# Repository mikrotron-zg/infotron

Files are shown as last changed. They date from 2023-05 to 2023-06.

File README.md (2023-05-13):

# Infotron

Simple info screen (e.g. LED matrix) displaying information from different web sources via wifi MCU (ESP32). This demo program allows you to display:
* time and date, 
* weather info, 
* custom text,
* or anything else you program it to display :wink:

Infotron runs its own little web server and web application that allows you to choose what to display. You can acces it via smartphone, tablet or notebook, by connecting directly to Infotron's access point (AP) or through your local network. Open your favorite browser and enter the IP address that Infotron scrolls at startup and have some fun _(Note: if you're not connecting to Infotron's AP, you'll have to find out the IP address it's assigned by your router first_).

## 1. Hardware

This project is built around two main components:
* [D1 MINI ESP32](https://www.diykits.eu/products/p_11918)
* [MAX7219 4-in-1 LED Matrix Display](http://www.diykits.eu/products/p_10987)

### 1.1. Wiring

Wiring is simple, follow the instructions in main.cpp, use fritzing file in _doc_ directory or the image below for reference:

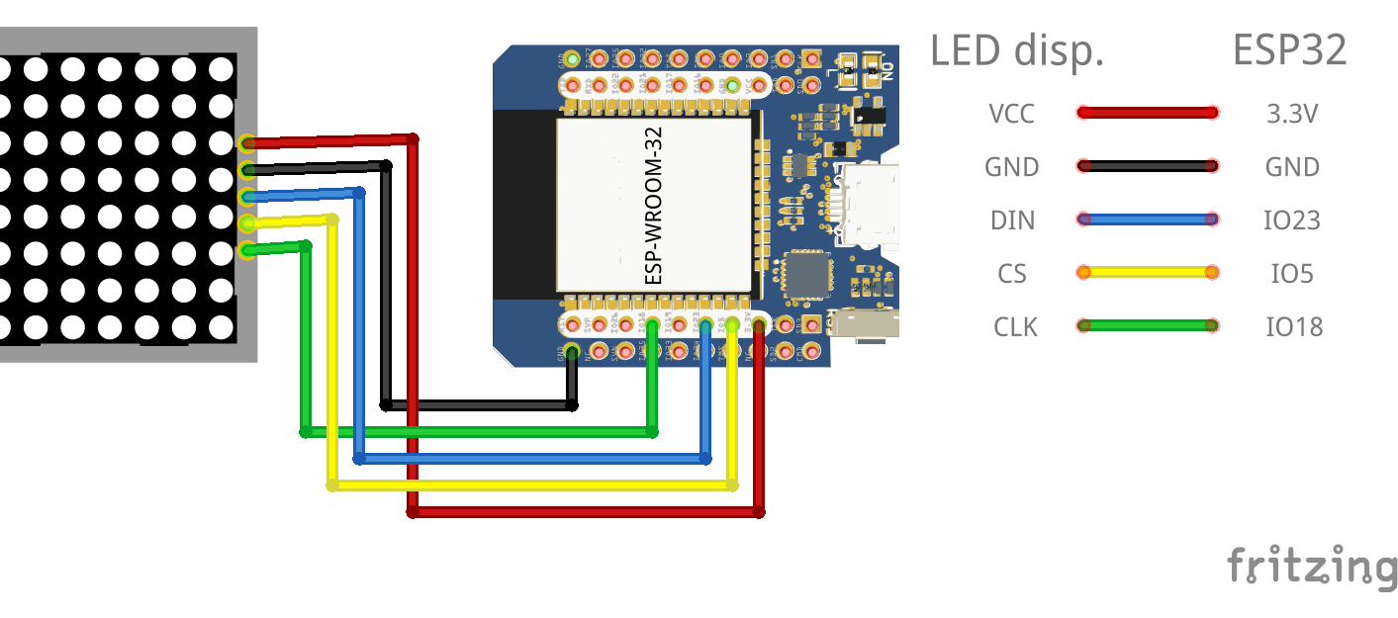
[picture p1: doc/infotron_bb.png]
Infotron wiring


You can solder the wires directly or use the provided angle headers and dupont wires for connection. Once in a box, it should look like this:

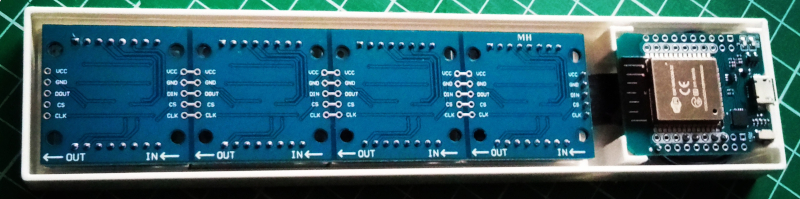
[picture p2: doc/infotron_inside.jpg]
Infotron box inside


### 1.2. Box

The box is 3D printed, 3D model was made using [OpenSCAD](https://openscad.org/) and source files are in _model_ directory. Final version of STLs will be there too, you'll have to use OpenSCAD (it's free and open source) to generate STLs. It's recommended to print in PETG, but any other filament type should be fine.

## 2. Software

To change, compile and upload this firmware, you'll need [VS Code](https://code.visualstudio.com/) and [PlatformIO plugin](https://platformio.org/). Make sure to build the filesystem image of _data_ directory and upload it to the boards SPIFFS too, as it contains the web application files needed to control Infotron. You can find out more about it [here](https://esp32tutorials.com/esp32-esp-idf-spiffs-web-server/).

### 2.1. Dependencies

The libraries used:
* [MD_Parola library](https://github.com/MajicDesigns/MD_Parola) by Marco Colli ([MajicDesigns](https://github.com/MajicDesigns))
* [MD_MAX72xx library](https://github.com/MajicDesigns/MD_MAX72xx) by Marco Colli ([MajicDesigns](https://github.com/MajicDesigns))
* [ESP Async WebServer](https://github.com/me-no-dev/ESPAsyncWebServer?utm_source=platformio&utm_medium=piohome) by [Hristo Gochkov](https://github.com/me-no-dev)

## 3. Status

Demo program on main branch works for the hardware listed above. The old (unfinished) version based on ESP8266 board can be found on branch _esp8266_.

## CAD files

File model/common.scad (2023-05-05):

/*
 * A library of common modules, functions and variables
 * This file is part of Infotron project (https://github.com/mikrotron-zg/infotron)
 * by Mikrotron d.o.o. (http://mikrotron.hr)
 *
 * This program is free software: you can redistribute it and/or modify
 * it under the terms of the GNU General Public License as published by
 * the Free Software Foundation, either version 3 of the License, or
 * (at your option) any later version. See the LICENSE file at the 
 * top-level directory of this distribution for details 
 *
 * This program is distributed in the hope that it will be useful,
 * but WITHOUT ANY WARRANTY; without even the implied warranty of
 * MERCHANTABILITY or FITNESS FOR A PARTICULAR PURPOSE.  See the
 * GNU General Public License for more details.
 *
 * You should have received a copy of the GNU General Public License
 * along with this program.  If not, see <https://www.gnu.org/licenses/>.
 */

// Extra dimension to remove ambiguity of walls
ex = 0.001;

// Hole dimension correction - if 3D printed holes turn out too small,
// increase the value (e.g. 1.1 = 110%), or reduce the value (e.g. 0.9 = 90%).
// Default value is 1.0 (100%)
hdc = 1.1;

// Some nuts and bolts dimensions
m3_bolt_head_dia = 6*hdc;
m3_bolt_head_height = 2;
m3_dia = 3*hdc;


module rounded_rect(x, y, z, radius = 1) {
    // Draws a rounded rectangle
    translate([radius,radius,0]) //move origin to outer limits
	linear_extrude(height=z)
		minkowski() {
			square([x-2*radius,y-2*radius]); //keep outer dimensions given by x and y
			circle(r = radius, $fn=100);
		}
}


module cylinder_quarter(r, h){
    // Draws quarter of a cylinder
    difference(){
        cylinder(r=r, h=h);
        translate ([-r-ex, -r-ex, -ex]) cube([2*r + 2*ex, r + ex, h + 2*ex]);
        translate ([-r-ex, -ex, -ex]) cube([r + ex, r + ex, h + 2*ex]);
    }
}


module header_pin(rows=1, columns=1){
    // Draws 2.54 mm male header pins
    base_width = 2.54;
    base_height = 2.54;
    header_width = 0.508;
    header_height = 5.08;
    trans = base_width/2 - header_width/2;

    for (i = [0: rows - 1]){
        for (j = [0: columns -1]){
            translate([j*base_width, i*base_width, 0]){
                color("Black") cube([base_width, base_width, base_height]);
                translate([trans , trans, base_height])
                    color("Khaki") cube([header_width, header_width, header_height]);
            }
        }
    }

}

module m3_bolt(length = 10){
    // M3 bolt mockup
    union(){
        cylinder(d = m3_dia, h = length);
        translate([0, 0, length - ex - m3_bolt_head_height]) 
            cylinder(d = m3_bolt_head_dia, h = m3_bolt_head_height + ex);
    }
}

module m3_nut_trap(){
    // Makes M3 nut trap inset
    cylinder(r=5.5/2/cos(180/6)*hdc, h=2, $fn=6);
}

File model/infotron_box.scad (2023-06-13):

/*
 * Infotron box 3D model
 * This file is part of Infotron project (https://github.com/mikrotron-zg/infotron)
 * by Mikrotron d.o.o. (http://mikrotron.hr)
 *
 * This program is free software: you can redistribute it and/or modify
 * it under the terms of the GNU General Public License as published by
 * the Free Software Foundation, either version 3 of the License, or
 * (at your option) any later version. See the LICENSE file at the 
 * top-level directory of this distribution for details 
 *
 * This program is distributed in the hope that it will be useful,
 * but WITHOUT ANY WARRANTY; without even the implied warranty of
 * MERCHANTABILITY or FITNESS FOR A PARTICULAR PURPOSE.  See the
 * GNU General Public License for more details.
 *
 * You should have received a copy of the GNU General Public License
 * along with this program.  If not, see <https://www.gnu.org/licenses/>.
 */
 
include<led_matrix_32x8.scad>;
include<mini32.scad>;

// Box dimensions
wall = 1.6; // box wall width
wall2 = 1.25*wall; // thicker box wall
screen_border = 2*wall + 3.0; // screen border width
box_width = led_matrix_width + 2*screen_border;
box_length = screen_border + 4*led_matrix_width + 50;
box_top_height = led_matrix_height + led_matrix_offset + module_pcb_height + wall + 0.4; 
box_bottom_height = 4 + wall2;
box_overlap_height = 5;
box_overlap_tolerance = wall/4;
slit_height = 1.5;
slit_width = wall/2;

// ESP32 mount dimensions
esp32_mount_width = 6;
esp32_mount_height = box_top_height - wall2;
esp32_mount_offset = 1;
esp32_mount_corner = esp32_mount_width - esp32_mount_offset;

// Entry point
infotron_box();

module infotron_box(){
    // Draws bottom and top part of the box, comment out one or the other for single object
    draw_bottom();
    translate([0, 1.2*box_width, 0]) draw_top();
}

module draw_bottom() {
    color ("White") difference() {
        union(){
            bottom_shell();
            // Overlap wall
            translate([wall, wall, wall2]) overlap();
            translate([box_length, box_width/2 - mini32_width/2, wall2]) 
                esp32_fixers();
            translate([screen_border + led_matrix_width/2 - esp32_mount_width/2,
                        box_width/2 - esp32_mount_width/2, wall2])
                led_matrix_fixers();
        }
        // USB cutout
        translate([box_length - 2*wall - ex, 
                   box_width/2 - mini32_usb_width/2 - 1,
                   box_bottom_height - mini32_usb_height])
            cube([3*wall, mini32_usb_width + 2, mini32_usb_height + ex]);
        // Removing corners
        translate([0, 0, box_bottom_height]) 
            cube([4*wall, 4*wall, box_overlap_height + ex]);
        translate([0, box_width - 4*wall, box_bottom_height]) 
            cube([4*wall, 4*wall, box_overlap_height + ex]);
        // Vent grill
        translate([box_length - 0.85*mini32_length, box_width/5, -ex]) {
            for (y = [0 : 5 : 3*box_width/5]) {
                translate([0, y, 0]) rounded_rect(0.75*mini32_length, 2.5, wall2 + 2*ex, 1);
            }
        }
    }
}

module bottom_shell() {
    difference(){
        rounded_rect(box_length, box_width, box_bottom_height);
        translate([wall, wall, wall2])
             cube([box_length - 2*wall, box_width - 2*wall, 
                    box_bottom_height - wall2 + ex]);
        translate([box_length*0.25, box_width/2, -ex]) wall_mount();
        translate([box_length*0.75, box_width/2, -ex]) wall_mount();
    }
}

module wall_mount() {
    $fn = 100;
    slit_width = 4;
    slit_length = 2;
    opening_dia = 8;
    translate([0, slit_length/4 + slit_width/4 + opening_dia/4]) {
        cylinder(d = slit_width, h = box_bottom_height + 2*ex);
        translate([-slit_width/2, -slit_length - slit_width/2 - opening_dia/2, 0]) 
            cube([slit_width, slit_length + slit_width/2 + opening_dia/2, box_bottom_height + 2*ex]);
        translate([0, -slit_length - opening_dia/2, 0])
            cylinder(d = opening_dia, h = box_bottom_height + 2*ex);
    }
}

module overlap() {
    inner_wall_height = box_bottom_height - wall2;
    difference() {
        cube([box_length - 2*wall, box_width - 2*wall, 
                inner_wall_height]);
        translate([wall, wall, -ex])
            cube([box_length - 2*wall, box_width - 4*wall,
                   inner_wall_height + 2*ex]);
    }
    translate([box_overlap_tolerance, box_overlap_tolerance, inner_wall_height])
    difference() {
        cube([box_length - 2*wall - 2*box_overlap_tolerance, 
                box_width - 2*wall - 2*box_overlap_tolerance, box_overlap_height]);
         translate([wall - box_overlap_tolerance, wall - box_overlap_tolerance, -ex])
            cube([box_length - 2*wall, box_width - 4*wall, box_overlap_height + 2*ex]);
    }
    translate([0, 0, inner_wall_height + box_overlap_height - 0.75*slit_height]) clips();
}

module clips() {
    clip_length = 5;
    translate([box_overlap_tolerance, box_width/2 - wall - clip_length/2, 0])
        rotate(90) clip(clip_length);
    for (i = [1 : 5]) {
        translate([i*(box_length - 2*wall)/6, -slit_width + box_overlap_tolerance, 0])
            clip(clip_length);
        translate([i*(box_length - 2*wall)/6, box_width - 2*wall - box_overlap_tolerance, 0]) 
            clip(clip_length);
    }
}

module clip(length) {
    cube([length, slit_width, 0.75*slit_height]);
}

module draw_top(){
    color ("White") {
        top_shell();
        translate([screen_border - wall, screen_border - wall, wall]) screen_bracket();
        translate([box_length - wall, box_width/2 + mini32_width/2, wall2])
            rotate(180) esp32_mount();
    }
    translate([screen_border, screen_border + led_matrix_width, led_matrix_height + led_matrix_offset + module_pcb_height]) 
            rotate([180, 0, 0]) %led_matrix_32x8();
    translate([box_length - wall, box_width/2 + mini32_width/2, box_top_height - mini32_height])
            rotate(180) %mini32();
}

module top_shell(){
    difference(){
        rounded_rect(box_length, box_width, box_top_height);
        translate([wall, wall, wall2])
            cube([box_length - 2*wall, box_width - 2*wall, box_top_height - wall2 + ex]);
        // Slit
        translate([slit_width, slit_width, box_top_height - box_overlap_height])
            cube([box_length - 2*slit_width, box_width - 2*slit_width, slit_height]);
        // Screen diffuser
        translate([screen_border, screen_border, 0.4])
            cube([4*led_matrix_width, led_matrix_width, wall2 + 2*ex]);
        // Engraved text
        translate([box_length - 50/2, box_width - screen_border, -ex]) top_text();
    }
}

module screen_bracket(bracket_height = 4){
    // Draw bracket
    difference(){
        cube([4*led_matrix_width + 2*wall, led_matrix_width + 2*wall, bracket_height]);
        translate([wall, wall, -ex])
            cube([4*led_matrix_width, led_matrix_width, led_matrix_width + 2*ex]);
    }
}

module top_text(){
    rotate([180, 0, 0]) translate([0, 0, -0.6]) linear_extrude(height = 0.6)
        text("infotron", size = 8, font = "Liberation Sans", halign = "center",                valign = "bottom");
}

module esp32_mount() {
    translate([mini32_length - esp32_mount_corner, -esp32_mount_offset, 0])
        esp32_pillar_mount();
    translate([mini32_length + esp32_mount_offset, mini32_width - esp32_mount_corner, 0])
        rotate(90) esp32_pillar_mount();
    translate([0, -esp32_mount_offset, 0]) difference() {
        cube([esp32_mount_corner, mini32_width - mini32_reset_width + 2*esp32_mount_offset, esp32_mount_height]);
        translate([0, esp32_mount_offset, esp32_mount_height - mini32_height])
            cube([esp32_mount_corner, mini32_width - mini32_reset_width, mini32_height + ex]);
    }
}

module esp32_pillar_mount() {
    difference() {
        cube([esp32_mount_width, esp32_mount_width, esp32_mount_height]);
        translate([0, 1, esp32_mount_height - mini32_height])
            cube([esp32_mount_corner, esp32_mount_corner, mini32_height + ex]);
    }
}

module esp32_fixers() {
    translate([-mini32_length - esp32_mount_offset, -esp32_mount_offset, 0])
        cube([esp32_mount_width, esp32_mount_width, box_bottom_height - wall2]);
    translate([-mini32_length - esp32_mount_offset, 
                mini32_width - esp32_mount_width + esp32_mount_offset, 0])
        cube([esp32_mount_width, esp32_mount_width, box_bottom_height - wall2]);
}

module led_matrix_fixers() {
    for (i = [0 : 3]) {
        translate([i*led_matrix_width, 0, 0])
            cube([esp32_mount_width, esp32_mount_width, box_bottom_height - wall2]);
    }
}

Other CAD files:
model/led_matrix_32x8.scad
model/mini32.scad

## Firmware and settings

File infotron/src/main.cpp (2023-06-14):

/*
 * This file is part of Infotron project (https://github.com/mikrotron-zg/infotron)
 * developed by Mikrotron d.o.o. (http://mikrotron.hr).
 * This is the main program file with setup and main program loop.
 *
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
 * You should have received a copy of the GNU General Public License
 * along with this program.  If not, see <https://www.gnu.org/licenses/>.
 */

#include <Arduino.h>
#include <MD_Parola.h> 
#include <MD_MAX72xx.h>
#include <SPI.h>
#include "Configuration.h"
#include "WebServer.h"
#include "DateTimeHandler.h"
#include "CryptoInfo.h"

/* 
  Define the number of devices we have in the chain and the hardware interface SPI connection pins
  NOTE: These pin numbers are for D1 MINI ESP 32 hardware SPI and will probably not
        work with different hardware and may need to be adapted
*/
#define HARDWARE_TYPE MD_MAX72XX::FC16_HW // works only with MD_MAX72xx 3.0.0 and up
#define MAX_DEVICES   4   // number of 8x8 LED matrix displays in use
#define CLK_PIN       18  // pinout tag: SCK
#define DATA_PIN      23  // pinout tag: MOSI
#define CS_PIN        5   // pinout tag: SS

MD_Parola screen = MD_Parola(HARDWARE_TYPE, CS_PIN, MAX_DEVICES);
DisplayMode displayMode = TEXT;

// Scrolling parameters
uint8_t frameDelay = 30;    // default frame delay value
textEffect_t scrollEffect = PA_SCROLL_LEFT;
textPosition_t scrollAlign = PA_LEFT;

// Global message buffers
#define BUF_SIZE  1024 // buffer size that should be able to handle data, increase size if needed
char curMessage[BUF_SIZE] = {""}; // message currently on display
char newMessage[BUF_SIZE] = {"Infotron starting..."}; // next message to display
bool newMessageReceived = true;

// Global datetime container
uint16_t datetime[6] = {0, 0, 0, 0, 0, 0}; // day, month, year, hour, minute, second
bool datetimeUpdated = false;

// Global weather info container
WeatherInfo weatherInfo = {0, 0, 0, false, 0};

// Global crypto info container
CryptoInfo cryptoInfo[CRYPTO_NUM] = {{"BTC", 0, 0, 0},    // Bitcoin
                                     {"ETH", 0, 0, 0}};    // Ethereum
                                     //{"DOGE", 0, 0, 0}};  // Dogecoin
int currentCryptoInfo = -1; // index of crypto info currently on display
ulong cryptoInfoLastUpdated = 0; // last time crypto info was updated

/**
 * @brief Handles custom text display.
 * 
 * Reads the contents of newMessage and sets it as a  
 * current message to display, then scrolls the message 
 * on a display.
 */
void displayText() {
  if (newMessageReceived) {
    strcpy(curMessage, newMessage);
    newMessageReceived = false;
    screen.displayScroll(curMessage, scrollAlign, scrollEffect, frameDelay);
  }
}

/**
 * @brief Handles date/time display.
 * 
 * Displays date and time received from the web app.
 */
void displayDateTime() {
  // Handle date/time display
  if (datetimeUpdated) {
    validateTime();
    if (datetime[5] == 20 || datetime[5] == 40) { // show date
      sprintf(newMessage, "%02d.%02d.%04d.", datetime[0], datetime[1], datetime[2]);
      datetimeUpdated = false;
      screen.displayClear();
      screen.displayScroll(newMessage, scrollAlign, scrollEffect, frameDelay*1.5);
      return;
    }
    if (datetime[5]%2 == 0) { // show time
      sprintf(curMessage, "%02d:%02d", datetime[3], datetime[4]);
    } else {
      sprintf(curMessage, "%02d %02d", datetime[3], datetime[4]);
    }
    datetimeUpdated = false;
    screen.displayText(curMessage, PA_CENTER, screen.getSpeed(), 0, PA_NO_EFFECT, PA_NO_EFFECT);
  }
}

/**
 * @brief Handles weather info display.
 * 
 * Displays weather info received from external source.
 */
void displayWeatherInfo() {
  // Handle weather info display
  if (!weatherInfo.isValid) { // no internet connection or server failure
    sprintf(newMessage, "Can't access weather data");
    newMessageReceived = true;
    displayMode = TEXT;
    return;
  }

  if (weatherInfo.showing == 0) { // first time showing weather info
    sprintf(curMessage, "%d \xB0""C", weatherInfo.temp);
    screen.displayText(curMessage, PA_CENTER, screen.getSpeed(), MAX_SCREEN_TIME, PA_GROW_UP, PA_GROW_DOWN);
    weatherInfo.showing++;
    return;
  }

  switch (weatherInfo.showing) {
    case 1:
      sprintf(curMessage, "%d%% RH", weatherInfo.humidity);
      screen.displayText(curMessage, PA_CENTER, screen.getSpeed(), MAX_SCREEN_TIME, PA_GROW_UP, PA_GROW_DOWN);
      weatherInfo.showing++;
      break;
    case 2:
      sprintf(curMessage, "%dhPa", weatherInfo.pressure);
      screen.displayText(curMessage, PA_CENTER, screen.getSpeed(), MAX_SCREEN_TIME, PA_GROW_UP, PA_GROW_DOWN);
      weatherInfo.showing++;
      break;
    case 3:
      sprintf(curMessage, "%d \xB0""C", weatherInfo.temp);
      screen.displayText(curMessage, PA_CENTER, screen.getSpeed(), MAX_SCREEN_TIME, PA_GROW_UP, PA_GROW_DOWN);
      weatherInfo.showing = 1;
      break;
  }
}

/**
 * @brief Handles crypto info display.
 * 
 * Displays crypto info received from external source.
 */
void displayCryptoInfo() {
  if ((millis() - cryptoInfoLastUpdated) > CRYPTOINFO_UPDATE_INTERVAL) getCryptoInfo();
  currentCryptoInfo++;
  if (currentCryptoInfo >= CRYPTO_NUM) currentCryptoInfo = 0;
  char value[10];
  char change[10];
  dtostrf(cryptoInfo[currentCryptoInfo].value, 4, 2, value);
  dtostrf(cryptoInfo[currentCryptoInfo].change*100, 4, 2, change);
  sprintf(curMessage, "%s   $%s  (%s%%)", cryptoInfo[currentCryptoInfo].ticker, value, change);
  screen.displayScroll(curMessage, scrollAlign, scrollEffect, frameDelay);
}

/**
 * @brief Program entry point, runs only once.
 * 
 * Initializes the screen and starts web server.
 */
void setup() {
  // Read instructions on DEBUG_MODE in 'include/Debug.h' file
  #ifdef DEBUG_MODE
    Serial.begin(115200);
    delay(3000);
    DEBUGLN("Infotron started in debug mode");
  #endif

  // Mount SPIFFS file system
  if(!SPIFFS.begin()){
    DEBUGLN("SPIFFS mounting error");
  }

  // Initailizing MD_Parola
  screen.begin();
  screen.displayClear();
  screen.displaySuspend(false);

  // Show start message
  displayText();

  // Start web server
  startWebServer();
}

/**
 * @brief Program main loop.
 * 
 * Handles screen display mode.
 */
void loop() {
  if (screen.displayAnimate()) {
    switch (displayMode) {
      case TEXT:
        displayText();
        screen.displayReset();
        break;
      case DATETIME:
        displayDateTime();
        break;
      case WEATHER:
        displayWeatherInfo();
        break;
      case CRYPTO:
        displayCryptoInfo();
        screen.displayReset();
        break;
    } 
  }
}

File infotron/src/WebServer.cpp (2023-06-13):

/*
 * This file is part of Infotron project (https://github.com/mikrotron-zg/infotron)
 * developed by Mikrotron d.o.o. (http://mikrotron.hr).
 * It contains basic web server HTTP handling, needs files from data 
 * directory to be uploaded to ESP32 SPIFFS in order to work properly.
 *
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
 * You should have received a copy of the GNU General Public License
 * along with this program.  If not, see <https://www.gnu.org/licenses/>.
 */

#include <WiFi.h>
#include <AsyncTCP.h>
#include <HTTPClient.h>
#include "Configuration.h"
#include "WebServer.h"
#include "DateTimeHandler.h"
#include "WeatherInfo.h"
#include "CryptoInfo.h"

AsyncWebServer server(80);

/***********************************************************************
 *************************** HTTP handling *****************************
 ***********************************************************************/
void onRootRequest(AsyncWebServerRequest *request) {
  // Client root request
  IPAddress remote_ip = request->client()->remoteIP();
  DEBUG(remote_ip.toString()); DEBUG(" requested "); DEBUGLN(request->url());
  request->send(SPIFFS, "/index.html", "text/html"); // send back index page
}

void onCSSRequest(AsyncWebServerRequest *request) {
  // Client CSS request
  IPAddress remote_ip = request->client()->remoteIP();
  DEBUG(remote_ip.toString()); DEBUG(" requested "); DEBUGLN(request->url());
  request->send(SPIFFS, "/bootstrap.min.css", "text/css"); // send back CSS file
}

void onCSSMapRequest(AsyncWebServerRequest *request) {
  // Client CSS request
  IPAddress remote_ip = request->client()->remoteIP();
  DEBUG(remote_ip.toString()); DEBUG(" requested "); DEBUGLN(request->url());
  request->send(SPIFFS, "/bootstrap.min.css.map", "text/css"); // send back CSS map file
}

void onPostRequest(AsyncWebServerRequest *request) {
  // Client POST request
  DEBUGLN("Got post request");
  if (request->params() == 0) {
    DEBUGLN("No parameters in post request!");
    request->send(404);
    return;
  }
  AsyncWebParameter* p = request->getParam(0);
  String param = p->name();
  DEBUG("Parameter name: "); DEBUGLN(param); 
  DEBUG("Parameter value: "); DEBUGLN(p->value());

  // Handle parameters
  if (param == "text") {
    // show custom text
    strcpy(newMessage, p->value().c_str());
    newMessageReceived = true;
    if (displayMode == DATETIME) stopDateTime();
    displayMode = TEXT;
  } else if (param == "time") {
    // show datetime
    startDateTime(p->value());
    displayMode = DATETIME;
  } else if (param == "weather") {
    // show weather data
    getWeatherInfo();
    if (displayMode == DATETIME) stopDateTime();
    displayMode = WEATHER;
  } else if (param == "crypto") {
    getCryptoInfo();
    if (displayMode == DATETIME) stopDateTime();
    displayMode = CRYPTO;
  } else {
    DEBUGLN("Parameter unknown!");
    request->send(404);
    return;
  }

  request->send(200);
}

void onPageNotFound(AsyncWebServerRequest *request) {
  // Unknown request
  IPAddress remote_ip = request->client()->remoteIP();
  DEBUG(remote_ip.toString()); DEBUG(" requested "); DEBUGLN(request->url());
  request->send(404, "text/plain", "Page not found"); // send back 404
}

/***********************************************************************
 ***************************** Services ********************************
 ***********************************************************************/
void startAccessPoint() {
  // Start access point
  WiFi.softAP(INFOTRON_SSID, INFOTRON_PASS);
  DEBUG("AP is running, ESP32 IP address: "); DEBUGLN(WiFi.softAPIP());
  sprintf(newMessage, "My IP address: %d.%d.%d.%d", 
          WiFi.softAPIP()[0], WiFi.softAPIP()[1], WiFi.softAPIP()[2], WiFi.softAPIP()[3]);
  newMessageReceived = true;
}

bool startWiFiStation() {
  // Start WiFi station mode, connect to router
  if (WiFi.status() == WL_CONNECTED) return true; // already connected, nothing to do

  WiFi.begin(WIFI_SSID, WIFI_PASS);
  if (WiFi.waitForConnectResult() == WL_CONNECTED) {
    DEBUGLN("Connected to primary WiFi");
    return true;
  }

  WiFi.begin(ALTERNATE_WIFI_SSID, ALTERNATE_WIFI_PASS);
  if (WiFi.waitForConnectResult() == WL_CONNECTED) {
    DEBUGLN("Connected to alternate WiFi");
    return true;
  }

  DEBUGLN("Not connected to any WiFi, check credentials");
  return false;
}

void startWiFi(bool startSTA = false) {
  // Set WiFi mode and start AP (and STA if needed)
  WiFi.mode(WIFI_MODE_APSTA);
  startAccessPoint();
  if (startSTA) { // start STA mode only if needed
    startWiFiStation();
  }
}

void startWebServer() {
  // Start WiFi
  startWiFi(true);

  // HTTP requests handling
  server.on("/", HTTP_GET, onRootRequest); // root request
  server.on("/bootstrap.min.css", HTTP_GET, onCSSRequest); // CSS request
  server.on("/bootstrap.min.css.map", HTTP_GET, onCSSMapRequest); // CSS map request
  server.on("/infotron", HTTP_POST, onPostRequest);
  server.onNotFound(onPageNotFound); // anything else

  server.begin();
  DEBUGLN("HTTP server started");
}

String getApiResponse(String url, String headerName, String headerValue) {
  String response = "";

  // Return empty string if there is no WiFi connection
  if (!startWiFiStation()) return response;

  HTTPClient http;
  // CHECKME: adding header doesn't seem to work
  if (headerName != "") http.addHeader(headerName, headerValue);
  http.begin(url);
  int responseCode = http.GET();

  DEBUG("Response code: "); DEBUGLN(responseCode);
  if (responseCode > 0) { 
      response = http.getString();
      DEBUGLN(response);
  }

  return response;
}

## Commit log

2018-07-02 Added 3D model directory with common library and NOVA board mockup
    [common.scad, croduino_nova.scad]
2018-07-05 Croduino NOVA 3D model finished
    [croduino_nova.scad]
2018-07-08 Added 32x8 LED matrix mockup
    [led_matrix_32x8.scad]
2018-07-08 First version of Infotron box top part
    [croduino_nova.scad, infotron_box.scad, led_matrix_32x8.scad]
2018-10-17 Changed box model
    [infotron_box.scad, led_matrix_32x8.scad]
2021-10-08 Added diffuser to box top
    [infotron_box.scad]
2021-11-06 Clean up
    [infotron_box.scad]
2021-11-06 Updated readme for ESP32 version
2021-11-08 New box top model for ESP32
    [croduino_nova.scad, infotron_box.scad, led_matrix_32x8.scad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]
2021-11-09 Slightly increased box size
    [infotron_box.scad]
2022-09-08 Some tweaks to box design
    [infotron_box.scad]
2022-09-08 Change board definition for PlatformIO
2022-09-08 Fix scrolling text issues
    [main.cpp]
2022-09-18 Add debug and configuration header files to project
    [Configuration.h]
2022-09-18 Add wifi and web server handler
    [Configuration.h]
2022-09-20 Add display mode handler
    [Configuration.h]
2022-09-21 Add date/time handler
    [Configuration.h]
2022-09-23 Display weather info
    [Configuration.h]
2022-09-25 Change start sequence
    [Configuration.h]
2023-05-05 Add license info to OpenSCAD files
    [common.scad, infotron_box.scad, led_matrix_32x8.scad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]
2023-05-10 Add mount holes to box model
    [infotron_box.scad]
2023-05-11 Update license and comments for includes
    [Configuration.h]
2023-05-13 Add docs and update README
    [infotron.fzz]
2023-06-13 Add crypto info API call
    [Configuration.h, infotron_box.scad]
2023-06-13 Add vent grill to box 3D model
    [infotron_box.scad]
2023-06-14 Add crypto info auto update interval
    [Configuration.h]
